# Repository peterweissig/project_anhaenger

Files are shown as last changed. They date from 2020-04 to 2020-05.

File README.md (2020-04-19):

# Anhaenger
Zeichnungen und Ideen zum Reise- und Transportanhänger

## Ziele
Der Anhänger soll ein **Transportanhänger** bleiben. \
Es müssen also alle Einbauten entweder herausnehmbar oder wegklappbar sein.

Darüberhinaus soll er als Schlaf- und **Campinganhänger** genutzt werden. \
Hierfür benötigt er Fenster, eine Liegefläche und mind. einen Klapptisch.

## Skizzen

Details siehe [Skizzen](Skizzen/)

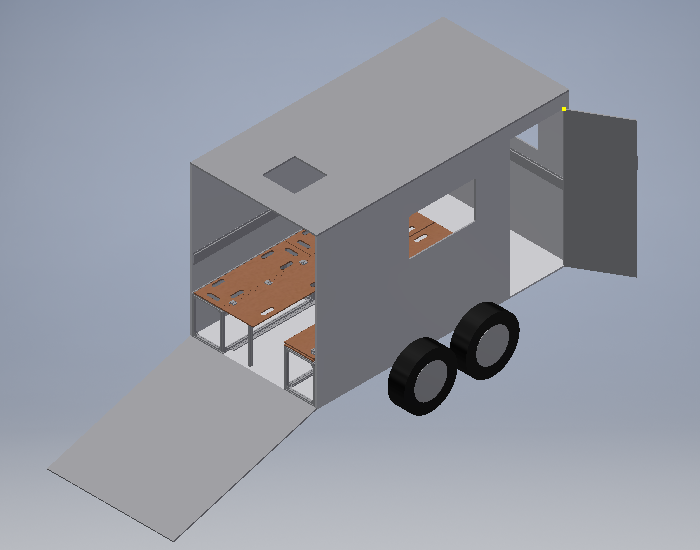
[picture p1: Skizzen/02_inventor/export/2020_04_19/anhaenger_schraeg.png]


## Aktueller Stand
Basis ist ein 2,0t Anhänger vom Humbaur:

* [HK 203015-18P](https://werksverkauf.humbaur.com/anhaenger/kofferanhaenger/kofferanhaenger-detailansicht/modell/hk-203015-18p)
* Innengröße (LxBxH): 3x1,5x1,8m
* Tonnage: 615kg (Leermasse) zu 2,0t
* 100km/h Zulassung (extra Stoßdämpfer)
* Tandemachse mit 15 Zoll Reifen
* Heckklappe für 500kg

Statische Einbauten:

* Dachfenster: Mini Heki von Dometic
* 2 Fenster: Dometic S4
* Klappbarer Tisch

Liege- und Sitzgruppe:

* Eigenkonstruktion
* 2 halbe Liegeflächen (2,20m x 0,75m)
* abklappbar zu 2 Sitzbänken (2,20m x 0,40m)
* je Seite 2 (unabhängige) Elemente (a 1,10m)

## Inspiration
### Dreamboxxx
[Artikel auf adventuremedia4u.de](https://www.adventuremedia4u.de/caravans/offroadanhaenger/dreamboxx.html) \
[Forenbeitrag bei Landcruiserfreunde.de](https://landcruiserfreunde.de/viewtopic.php?f=25&t=1255)

* Kleine Koffer zum Schlafen und Transportieren
* um 2011 _(Firma existiert evtl. nicht mehr)_

### lafalau
[Kurzbeschreibung mit Bildern](http://laufalau.com/10-camping) \
[Beitrag bei wohnwagen-forum.de](https://wohnwagen-forum.de/index.php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)
    
* Basis ist ein Tandem-Koffer von Unsinn
* Kühlkoffer (40mm PU isoliert)
* 3t zGG
* Boden zusätzlich: 20mm Dämmung & 18mm OSB-Platte
* Hinzugefügt: Seitentür, Seitenfenster, Dachfenster
* Einbauten: Küche, Heizung, Solarmodul, Markise,
  Duschkabine, Abwassertank, Windabweise mit Gasflaschen,
  Trittstufen, ...
* Solarzellen, Batterie, Management
* Kostenpunkt 19.300€
    * Airline Zurrschinen 4x2m: 170€
    * Matrazen 2x 80x200cm: 105€
    * Dometic Seitz S4 Fenster: 1.300€ \
      (2x Schlafen, 2x Wohnen, 2x Dachhaube)

### Godes Ausbaublog
[Beitrag bei womobox.de](http://www.womobox.de/phpBB2/viewtopic.php?t=7486)

* Basis ist ein Tandemkoffer
* Kühlkoffer (40mm PU isoliert)
* 3,5t zGG

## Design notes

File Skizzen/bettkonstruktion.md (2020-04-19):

# Bettkonstruktionen
## aktueller Entwurf (V3)
* [Technische Zeichnung](02_inventor/export/2020_04_19/bett_V3/bett_V3_zeichnung.pdf)
* Sitzreihe mit statischer Breite von **38cm**
* Klappteil
    * 36,5cm breit
    * ohne Rahmenkonstruktion aus Aluprofilen
    * wird **nach oben** weggeklappt
* Verbindung über 3 Plastewinkel mit 2 je Schraublöchern

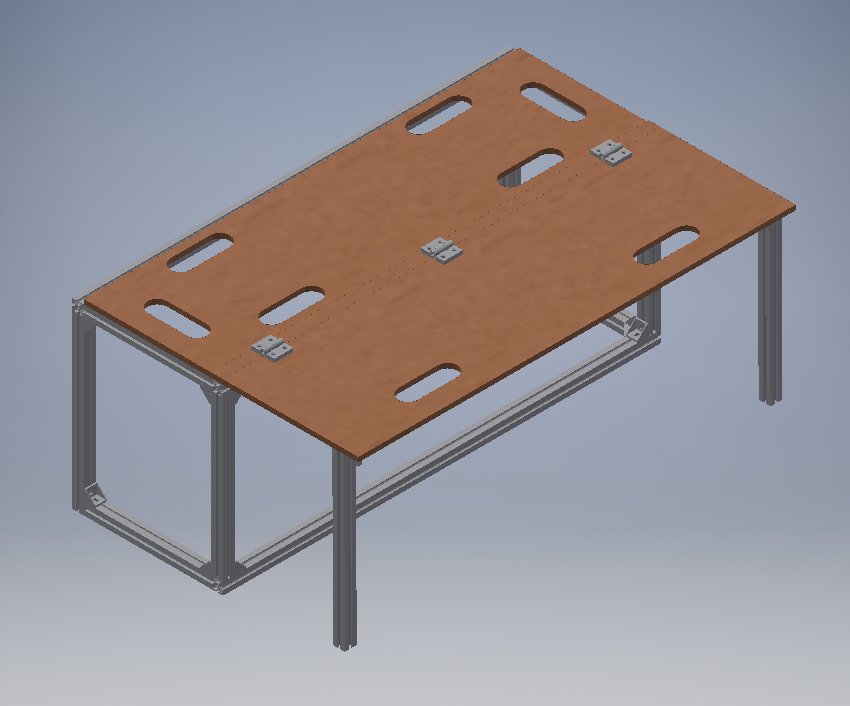
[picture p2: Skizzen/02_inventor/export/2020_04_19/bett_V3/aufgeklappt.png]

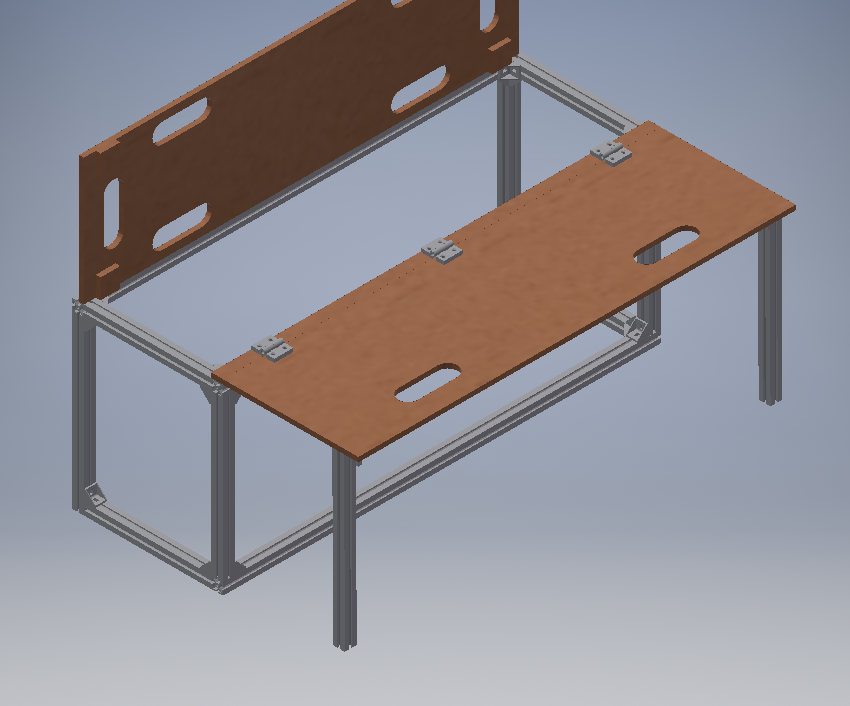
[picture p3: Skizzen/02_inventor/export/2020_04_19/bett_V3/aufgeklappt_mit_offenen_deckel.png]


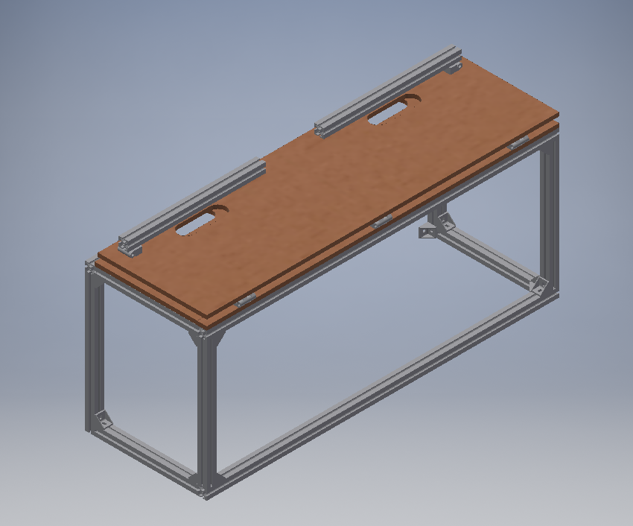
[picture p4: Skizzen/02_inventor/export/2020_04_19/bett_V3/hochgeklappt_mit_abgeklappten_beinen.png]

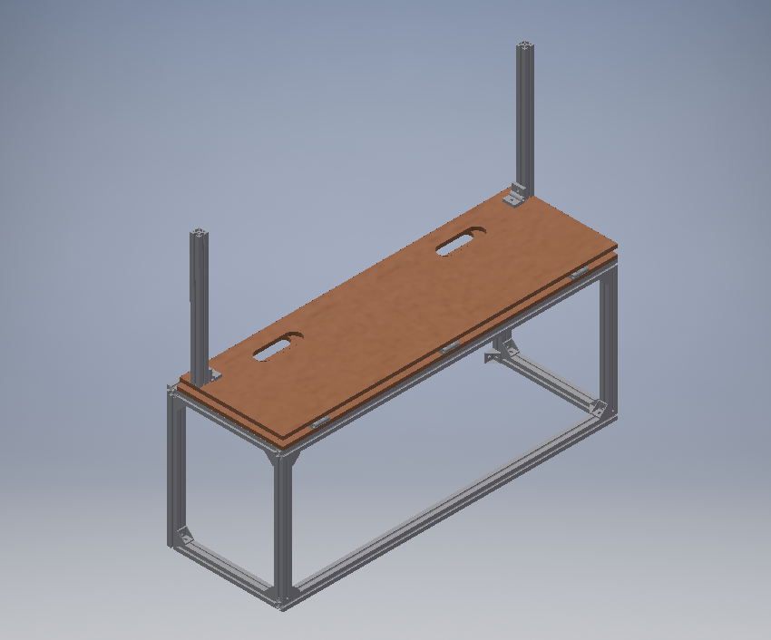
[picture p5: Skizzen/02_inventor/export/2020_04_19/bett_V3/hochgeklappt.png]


## Verison 2
* Sitzreihe mit statischer Breite von 36cm
* Klappteil
    * Rahmenkonstruktion aus Aluprofilen _(31cm breit)_
    * wird nach unten weggeklappt
    * _kann auch vertikal hochgeklappt werden_
* Verbindung über 2 (teure) Aluwinkel

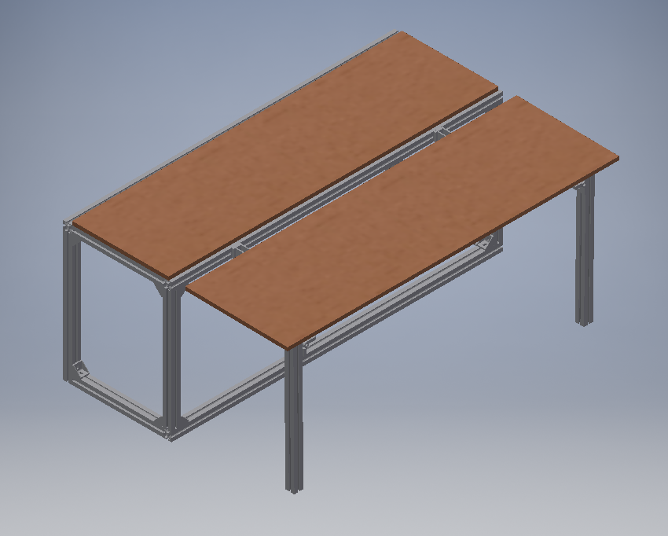
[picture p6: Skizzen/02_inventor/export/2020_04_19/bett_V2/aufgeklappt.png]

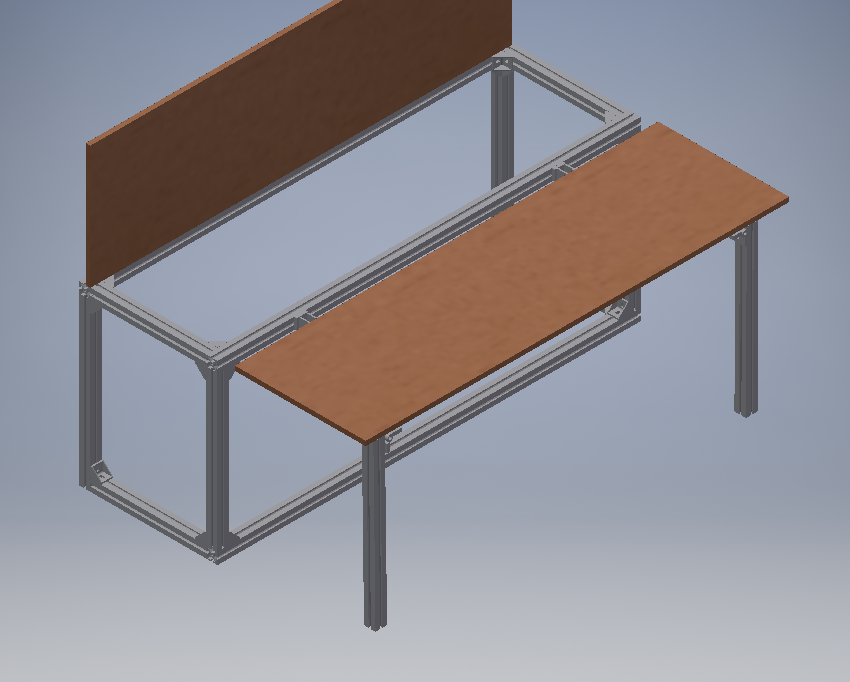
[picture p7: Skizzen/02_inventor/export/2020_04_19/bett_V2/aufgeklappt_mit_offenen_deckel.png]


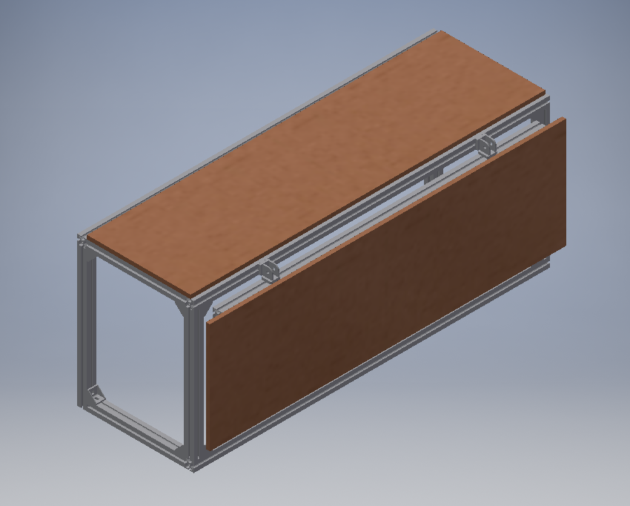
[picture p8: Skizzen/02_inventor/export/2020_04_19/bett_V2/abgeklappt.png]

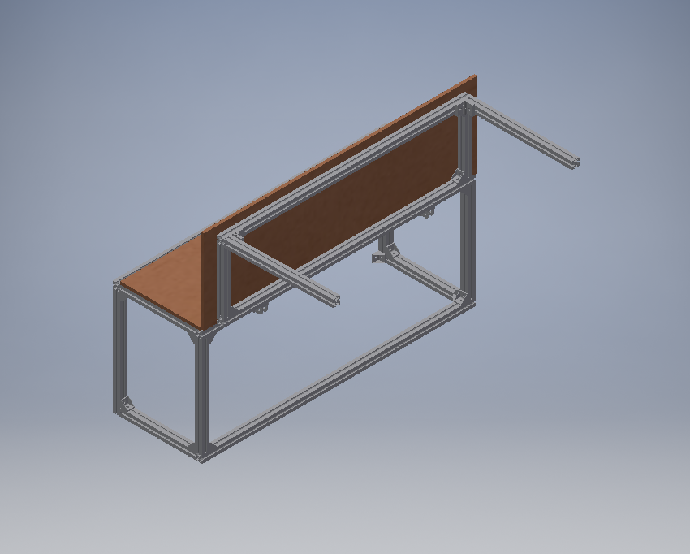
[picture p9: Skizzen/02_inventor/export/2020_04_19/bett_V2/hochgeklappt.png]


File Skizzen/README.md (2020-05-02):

# Skizzen des Anhängers

## aktueller Entwurf
* mit [Autodesk Inventor](https://de.wikipedia.org/wiki/Autodesk_Inventor)
* Tandemanhänger
* Seitentür rechts
* Fenster rechts und vorne
* mit Dachfenster
* [verschiedene Bettkonstruktionen](bettkonstruktion.md) aus Aluprofilen
* **die Konstruktion ist noch nicht fertig**



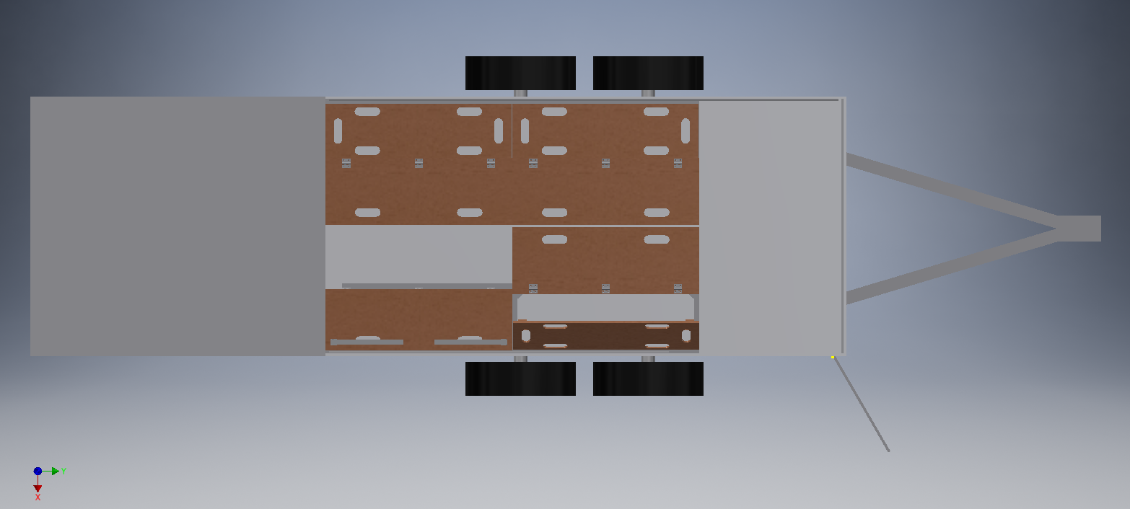
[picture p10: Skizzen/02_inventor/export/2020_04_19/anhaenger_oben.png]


## Erste Skizzen
* mit [SweetHome3D](http://www.sweethome3d.com/) gezeichnet - siehe auch [Ubuntu-Wiki](https://wiki.ubuntuusers.de/Sweet_Home_3D/)
* einachsiger Anhänger
* Seitentür rechts
* Fenster rechts und links
* kein Dachfenster
* Bettkonstruktion aus Holz und ähnlich der Dreamboxxx

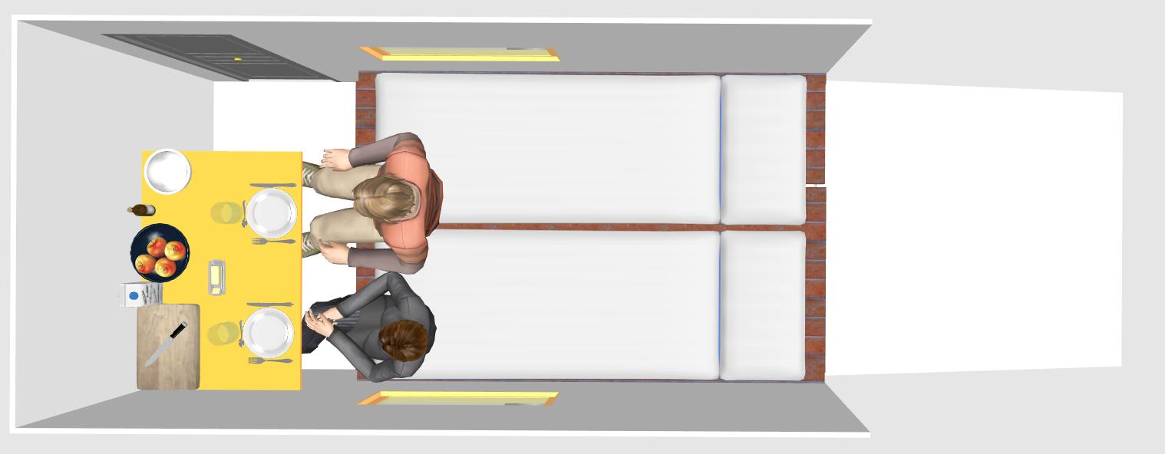
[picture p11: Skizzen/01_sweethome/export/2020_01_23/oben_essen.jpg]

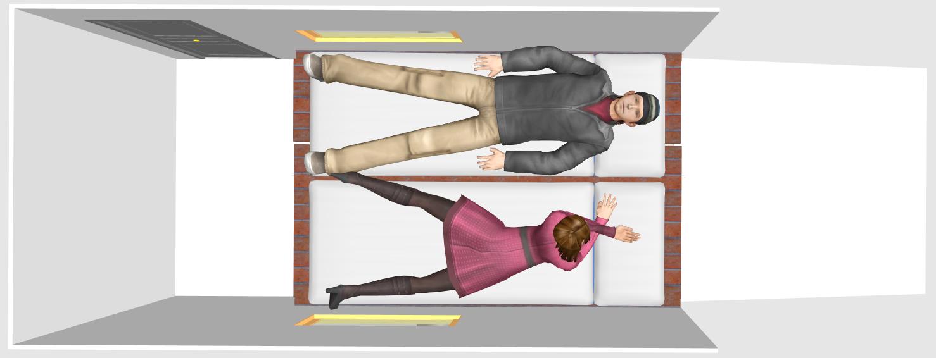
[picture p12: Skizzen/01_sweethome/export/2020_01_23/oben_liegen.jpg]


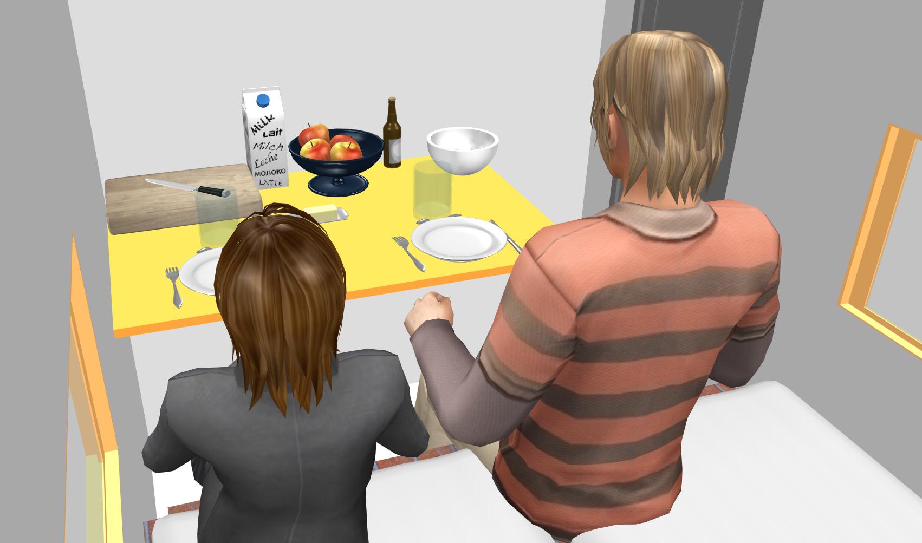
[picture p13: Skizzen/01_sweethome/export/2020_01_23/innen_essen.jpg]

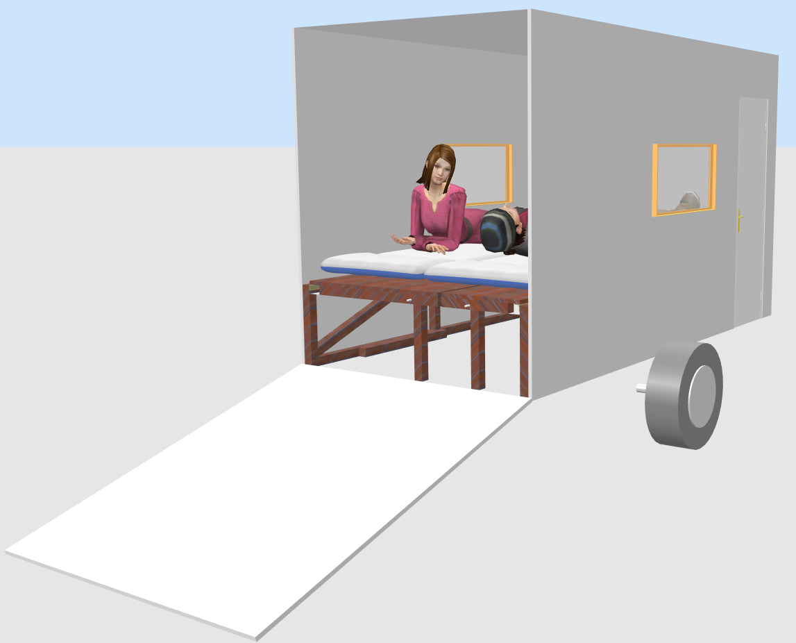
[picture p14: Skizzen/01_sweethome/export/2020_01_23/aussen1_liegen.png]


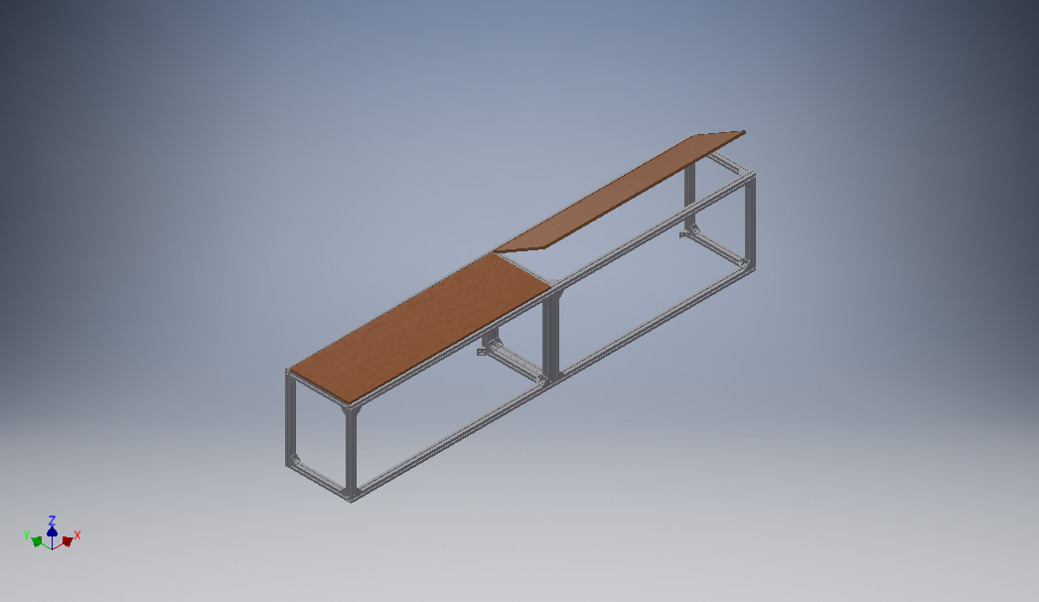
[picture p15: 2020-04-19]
Skizzen/02_inventor/export/2020_04_13/bett_V2_sitzbank_mit_deckel.png

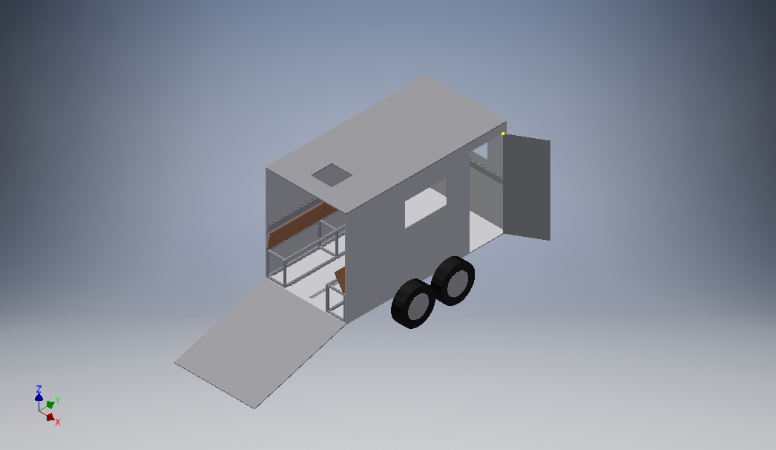
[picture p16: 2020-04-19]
Skizzen/02_inventor/export/2020_03_29/anhaenger_gesamt3.png

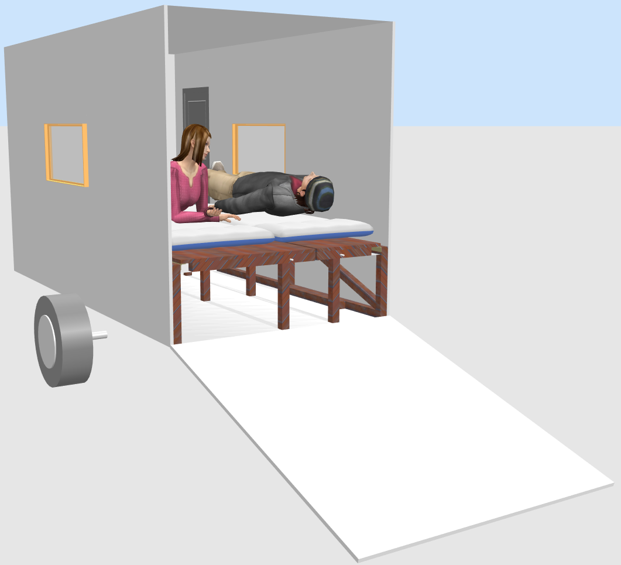
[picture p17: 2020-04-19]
Skizzen/01_sweethome/export/2020_01_23/aussen2_liegen.png

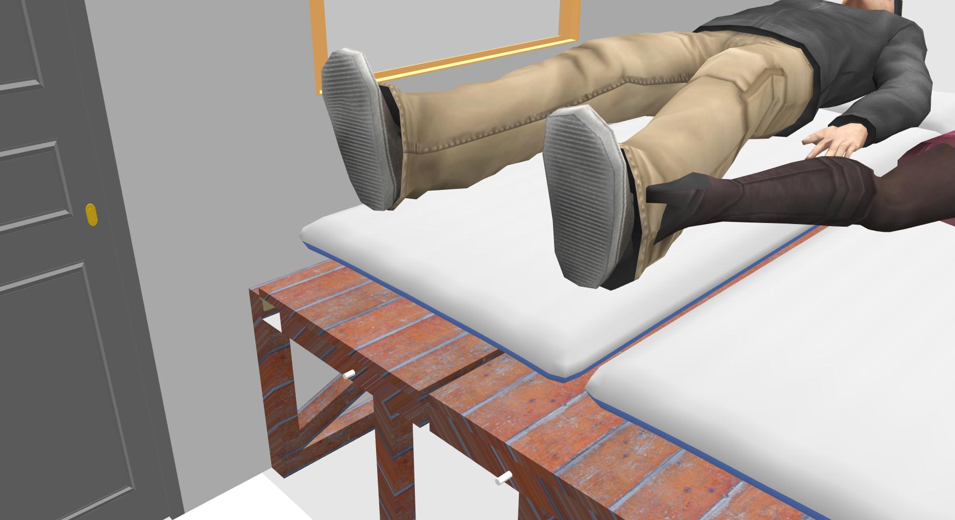
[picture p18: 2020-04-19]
Skizzen/01_sweethome/export/2020_01_23/innen_liegen.jpg

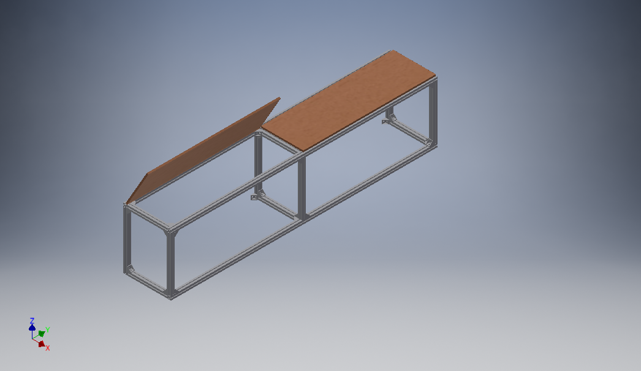
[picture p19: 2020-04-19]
Skizzen/02_inventor/export/2020_04_13/bett_V1_sitzbank_mit_deckel.png

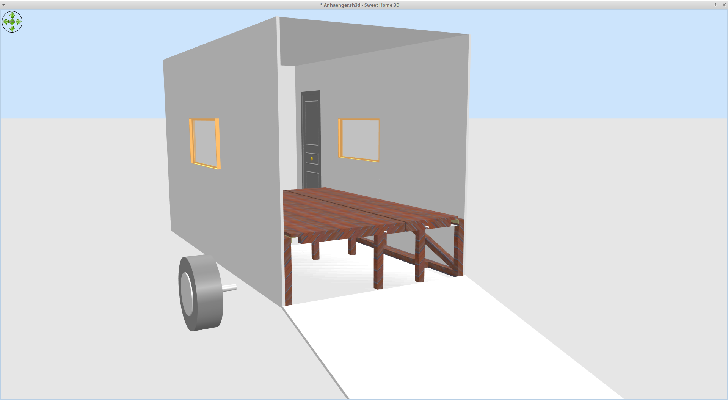
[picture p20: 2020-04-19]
Skizzen/01_sweethome/export/2020_01_22/screenshot/Ansicht_von_Aussen2_zu.png

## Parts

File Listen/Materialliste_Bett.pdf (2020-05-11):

## Bettgestell

Peter Weissig | Seite 1 von 2 | 11.05.2020
Bezeichnung | Art.-Nr. | pro Element | Gesamt | Einzelpreis | Gesamtpreis
63009-SZ1 | 5 | 20 | 9,60 € | 191,99 €
63009-SZ1 | 2 | 8 | 3,91 € | 31,28 €
63009-SZ1 | 2 | 8 | 3,88 € | 31,04 €
63009-STLS-0400 | 2 | 8 | 3,30 € | 26,41 €
63009-SZ1 | 4 | 16 | 2,97 € | 47,53 €
63009-SZ1 | 2 | 8 | 2,63 € | 21,03 €
349,28 €
Bezeichnung | Art.-Nr. | pro Element | Gesamt | Einzelpreis | Gesamtpreis
LP30107 | 2 | 8 | 0,87 € | 6,95 €
62514 | 2 | 8 | 2,10 € | 16,82 €
| 62385-BS | 30 | 120 | 1,64 € | 196,80 €
Bank | 20
Wandbefestigung | 2
Klappe | 4
Beine | 4
64006-1 | 5 | 20 | 2,40 € | 48,00 €
Klappe | 3
Beine | 2
| 62354-VK | 18 | 100 | 0,23 € | 23,39 €
Scharniere | 12 | *
Winkel Klappe | | 12
Beine | -6
| DIN7991-A2-M6X16 | 18 | 100 | 0,05 € | 4,95 €
Scharniere | 12 | *
Beine | 6
DIN7991-A2-M6X18 | 2 | 10 | 0,20 € | 2,03 €
Beine | 2 | *
| DIN7984-A2-M6X12 | 14 | 100 | 0,06 € | 6,43 €
Winkel | 10 | *
Beine | 4
305,37 €

* aufgerundet, da Verbauchsmaterial und/oder wegen Mengenrabatt

Bezeichnung | Art.-Nr. | pro Element | Gesamt | Einzelpreis | Gesamtpreis
62491 | 9,26 | 37 | 4,40 € | 162,80 €
Bank | 2,84 | *
Klappe | 2,76
Schutz Klappe | | 0,8
Schutz Beine | | 0,5
Schutz Rückwand | | 0,86
Schutz Seite | | 1,5
Versandkosten (ca.) | 1 | 1 | 19,66 € | 19,66 €
182,46 €

* leicht abgerundet, da Verkauf nur auf ganze Meter

Gesamtsumme der Bestellung | 837,11 €
Einzelpreis pro Element | 209,28 €

Aluprofil – 110 cm
Aluprofil – 43 cm
Aluprofil – 42,7 cm (https://www.dold-mechatronik.de/Aluminiumprofil-30x30L-I-Typ-Nut-6-ZUSCHNITT-bis-1200-mm-850-EUR-m-025-EUR-pro-Schnitt)
Aluprofil – 40 cm (https://www.dold-mechatronik.de/Aluminiumprofil-30x30L-I-Typ-Nut-6-Standardlaengen-825-EUR-m-400mm)
Aluprofil – 32 cm
Aluprofil – 28 cm (https://www.dold-mechatronik.de/Aluminiumprofil-30x30L-I-Typ-Nut-6-ZUSCHNITT-bis-1200-mm-850-EUR-m-025-EUR-pro-Schnitt)

Aluplatte – 3 Loch (https://www.dold-mechatronik.de/Verbinderplatte-58x58mm-3-Loch-Alu-gelasert)
Aluplatte – 8 Loch (https://www.dold-mechatronik.de/Verbinderplatte-58x118-8-loch-gelasert-blank)
Winkelsatz (https://www.dold-mechatronik.de/Winkel-30-I-Typ-Nut-6-inkl-Befestigungssatz)

Scharnier leicht (https://www.dold-mechatronik.de/Scharnier-Kunststoff-leicht-30-30_1)

Nutensteine (https://www.dold-mechatronik.de/Nutenstein-mit-Steg-I-Typ-Nut-6-Gewindedurchmesser-M6)

Schraube – 16mm Senkkopf (https://www.dold-mechatronik.de/DIN-7991-Senkschraube-mit-Innensechskant-A2-M6X16)

Schraube – 18mm Senkkopf (https://www.dold-mechatronik.de/DIN-7991-Senkschraube-mit-Innensechskant-A2-M6X18)

Schraube – 12mm Zylinderkopf (https://www.dold-mechatronik.de/DIN-7984-Zylinderschraube-mit-Innensechskant-und-niedrigem-Kopf-Edelstahl-A2-M6X12)

Abdeckung (https://www.dold-mechatronik.de/Abdeckprofil-Kunststoff-NBR-I-Typ-Nut-6-ca-1000-mm)

### https://www.dold-mechatronik.de/

## Deckplatten

Peter Weissig | Seite 2 von 2 | 11.05.2020

* alle Platten waren Zuschnitt im Hornbach für 30,71€/m²

Gesamtsumme | 99,32 €
Einzelpreis pro Element | 24,83 €

### https://www.hornbach.de/

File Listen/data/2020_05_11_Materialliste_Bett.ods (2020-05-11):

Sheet: Bettgestell
Bezeichnung | Art.-Nr. | pro Element | Gesamt | Einzelpreis | Gesamtpreis
Aluprofil – 110 cm (https://www.dold-mechatronik.de/Aluminiumprofil-30x30L-I-Typ-Nut-6-ZUSCHNITT-bis-1200-mm-850-EUR-m-025-EUR-pro-Schnitt) | 63009-SZ1 | 5 | 20 | 9,60 € | 191,99 €
Aluprofil – 43 cm (https://www.dold-mechatronik.de/Aluminiumprofil-30x30L-I-Typ-Nut-6-ZUSCHNITT-bis-1200-mm-850-EUR-m-025-EUR-pro-Schnitt) | 63009-SZ1 | 2 | 8 | 3,91 € | 31,28 €
Aluprofil – 42,7 cm (https://www.dold-mechatronik.de/Aluminiumprofil-30x30L-I-Typ-Nut-6-ZUSCHNITT-bis-1200-mm-850-EUR-m-025-EUR-pro-Schnitt) | 63009-SZ1 | 2 | 8 | 3,88 € | 31,04 €
Aluprofil – 40 cm (https://www.dold-mechatronik.de/Aluminiumprofil-30x30L-I-Typ-Nut-6-Standardlaengen-825-EUR-m-400mm) | 63009-STLS-0400 | 2 | 8 | 3,30 € | 26,41 €
Aluprofil – 32 cm (https://www.dold-mechatronik.de/Aluminiumprofil-30x30L-I-Typ-Nut-6-ZUSCHNITT-bis-1200-mm-850-EUR-m-025-EUR-pro-Schnitt) | 63009-SZ1 | 4 | 16 | 2,97 € | 47,53 €
Aluprofil – 28 cm (https://www.dold-mechatronik.de/Aluminiumprofil-30x30L-I-Typ-Nut-6-ZUSCHNITT-bis-1200-mm-850-EUR-m-025-EUR-pro-Schnitt) | 63009-SZ1 | 2 | 8 | 2,63 € | 21,03 €
 |  |  |  |  | 349,28 €
Bezeichnung | Art.-Nr. | pro Element | Gesamt | Einzelpreis | Gesamtpreis
Aluplatte – 3 Loch (https://www.dold-mechatronik.de/Verbinderplatte-58x58mm-3-Loch-Alu-gelasert) | LP30107 | 2 | 8 | 0,87 € | 6,95 €
Aluplatte – 8 Loch (https://www.dold-mechatronik.de/Verbinderplatte-58x118-8-loch-gelasert-blank) | 62514 | 2 | 8 | 2,10 € | 16,82 €
Winkelsatz (https://www.dold-mechatronik.de/Winkel-30-I-Typ-Nut-6-inkl-Befestigungssatz) | 62385-BS | 30 | 120 | 1,64 € | 196,80 €
Bank |  | 20
Wandbefestigung |  | 2
Klappe |  | 4
Beine |  | 4
Scharnier leicht (https://www.dold-mechatronik.de/Scharnier-Kunststoff-leicht-30-30_1) | 64006-1 | 5 | 20 | 2,40 € | 48,00 €
Klappe |  | 3
Beine |  | 2
Nutensteine (https://www.dold-mechatronik.de/Nutenstein-mit-Steg-I-Typ-Nut-6-Gewindedurchmesser-M6) | 62354-VK | 18 | 100 | 0,23 € | 23,39 €
Scharniere |  | 12 | *
Winkel Klappe |  | 12
Beine |  | -6
Schraube – 16mm Senkkopf (https://www.dold-mechatronik.de/DIN-7991-Senkschraube-mit-Innensechskant-A2-M6X16) | DIN7991-A2-M6X16 | 18 | 100 | 0,05 € | 4,95 €
Scharniere |  | 12 | *
Beine |  | 6
Schraube – 18mm Senkkopf (https://www.dold-mechatronik.de/DIN-7991-Senkschraube-mit-Innensechskant-A2-M6X18) | DIN7991-A2-M6X18 | 2 | 10 | 0,20 € | 2,03 €
Beine |  | 2 | *
Schraube – 12mm Zylinderkopf (https://www.dold-mechatronik.de/DIN-7984-Zylinderschraube-mit-Innensechskant-und-niedrigem-Kopf-Edelstahl-A2-M6X12) | DIN7984-A2-M6X12 | 14 | 100 | 0,06 € | 6,43 €
Winkel |  | 10 | *
Beine |  | 4
 |  |  |  |  | 305,37 €
* aufgerundet, da Verbauchsmaterial und/oder wegen Mengenrabatt
Bezeichnung | Art.-Nr. | pro Element | Gesamt | Einzelpreis | Gesamtpreis
Abdeckung (https://www.dold-mechatronik.de/Abdeckprofil-Kunststoff-NBR-I-Typ-Nut-6-ca-1000-mm) | 62491 | 9,26 | 37 | 4,40 € | 162,80 €
Bank |  | 2,84 | *
Klappe |  | 2,76
Schutz Klappe |  | 0,8
Schutz Beine |  | 0,5
Schutz Rückwand |  | 0,86
Schutz Seite |  | 1,5
Versandkosten (ca.) |  | 1 | 1 | 19,66 € | 19,66 €
 |  |  |  |  | 182,46 €
* leicht abgerundet, da Verkauf nur auf ganze Meter
https://www.dold-mechatronik.de/ |  | Gesamtsumme der Bestellung |  |  | 837,11 €
 |  | Einzelpreis pro Element |  |  | 209,28 €

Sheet: Deckplatten
Bezeichnung | Anzahl | Länge in cm | Breite in cm | Fläche in m² | Einzelpreis | Gesamtpreis
Siebdruckplatte 12mm (https://www.hornbach.de/shop/Siebdrucksperrholz-Birke-Sieb-Film-1250x2500x12-mm-Zuschnitt-online-reservierbar/5017757/artikel.html) | 4 | 110 | 37,5 | 0,4125 | 12,67 € | 50,68 €
Siebdruckplatte 12mm (https://www.hornbach.de/shop/Siebdrucksperrholz-Birke-Sieb-Film-1250x2500x12-mm-Zuschnitt-online-reservierbar/5017757/artikel.html) | 4 | 110 | 36 | 0,396 | 12,16 € | 48,64 €
 |  |  |  |  |  | 99,32 €
* alle Platten waren Zuschnitt im Hornbach für 30,71€/m²
https://www.hornbach.de/ |  | Gesamtsumme |  |  |  | 99,32 €
 |  | Einzelpreis pro Element |  |  |  | 24,83 €

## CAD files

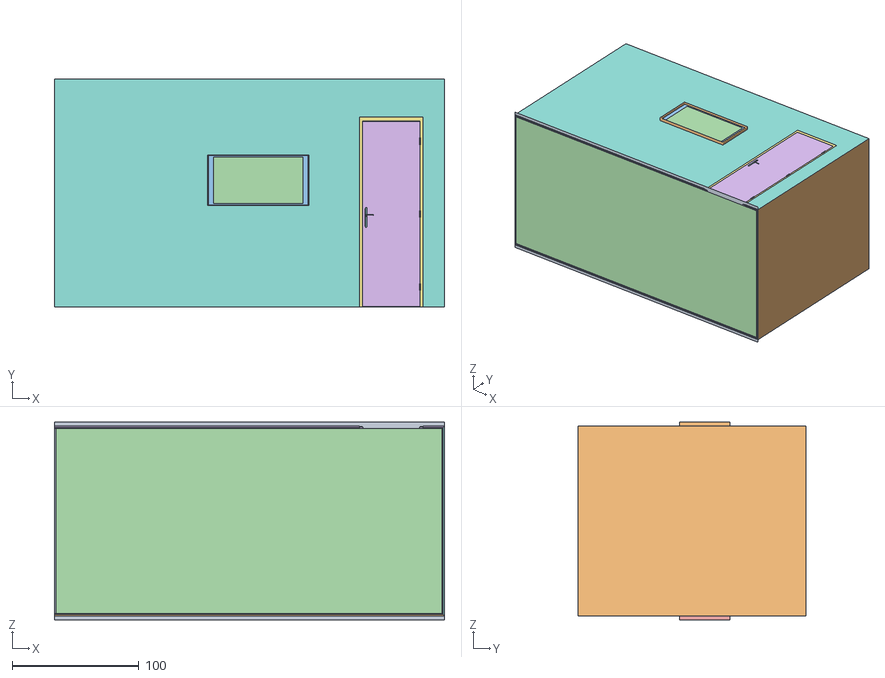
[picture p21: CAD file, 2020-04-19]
Skizzen/01_sweethome/details/anhaenger/teil1_grundkoerper/anhaenger_aufbau_teil1.obj
308.0 x 180.0 x 156.0
ground_1
wall_1_2
wall_1_3
wall_1_4
wall_1_5
wall_1_6
wall_1_7
wall_2_8
wall_2_9
wall_2_10
wall_2_11
wall_2_12
wall_2_13
wall_3_14
wall_3_15
wall_3_16
wall_3_17
wall_3_18
wall_3_19
room_4_20
room_4_21
frameOutside_22
frame_23
sweethome3d_hinge_1_3_2_24
sweethome3d_hinge_1_3_25
sweethome3d_hinge_1_2_2_26
sweethome3d_hinge_1_2_27
sweethome3d_hinge_1_1_2_28
sweethome3d_hinge_1_1_29
sweethome3d_opening_on_hinge_1_door_30
sweethome3d_opening_on_hinge_1_handle_7_31
sweethome3d_opening_on_hinge_1_handle_32
sweethome3d_opening_on_hinge_1_doorOutside_33
Tour_Fenetre_34
Fenetre_1_35
sweethome3d_window_pane_36
Tour_Fenetre_37
Fenetre_1_38
sweethome3d_window_pane_39

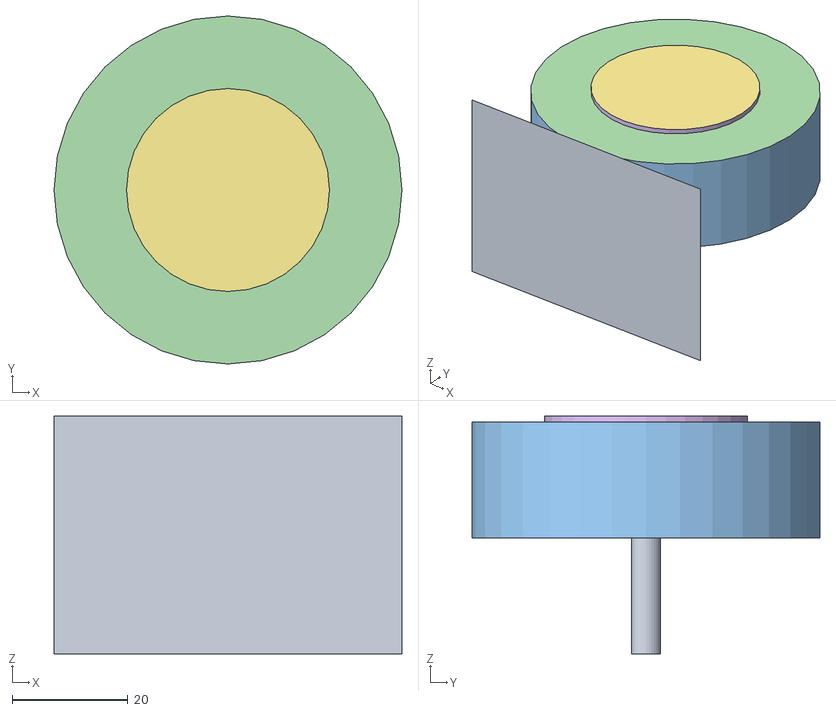
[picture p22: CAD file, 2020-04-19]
Skizzen/01_sweethome/details/anhaenger/teil2_raeder/anhaenger_aufbau_teil2.obj
60.0 x 60.0 x 41.0
ground_1

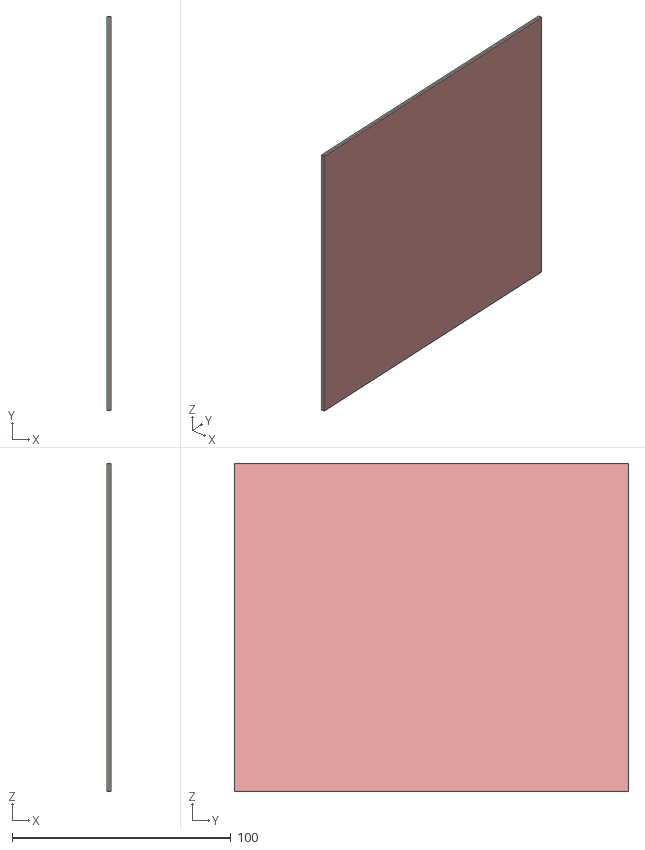
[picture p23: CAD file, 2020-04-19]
Skizzen/01_sweethome/details/anhaenger/teil3_heckklappe/anhaenger_aufbau_teil3.obj
2.00 x 180.0 x 150.0
ground_1
wall_1_2
wall_1_3
wall_1_4
wall_1_5
wall_1_6
wall_1_7

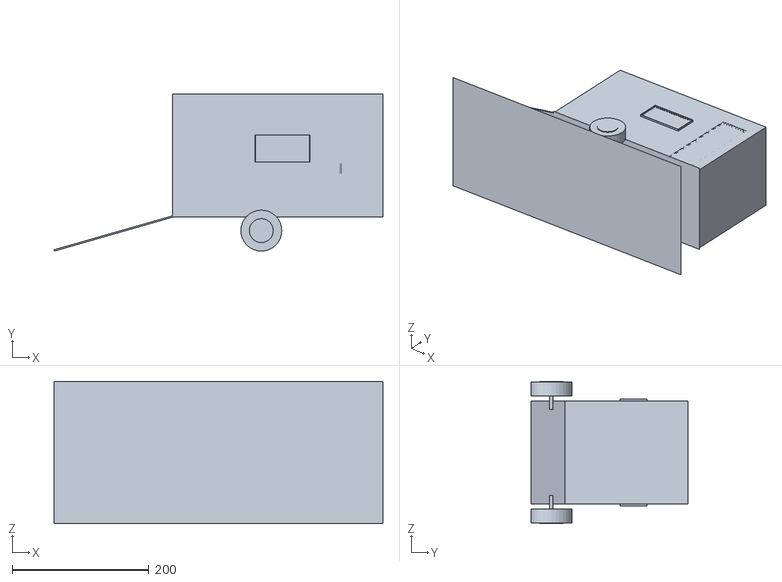
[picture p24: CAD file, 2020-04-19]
Skizzen/01_sweethome/details/anhaenger_aufgeklappt.obj
481.3 x 230.0 x 208.0

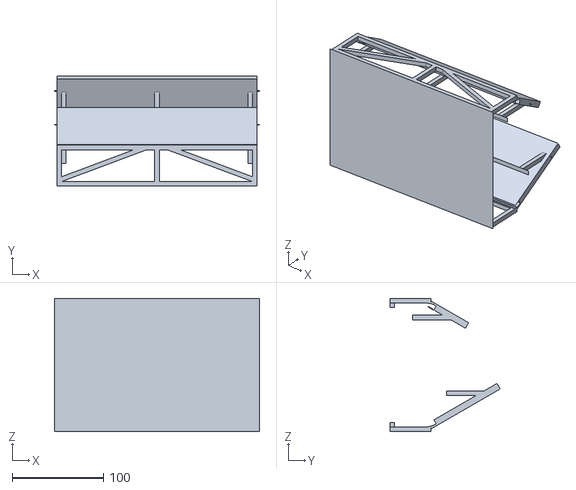
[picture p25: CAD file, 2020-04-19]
Skizzen/01_sweethome/details/bettgestell/anhaenger_bettgestell_aufgeklappt.obj
225.0 x 121.2 x 146.0

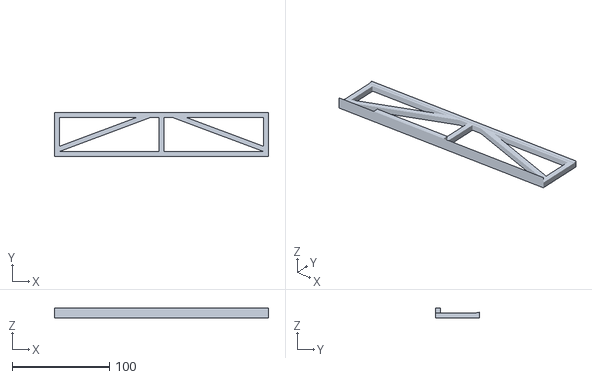
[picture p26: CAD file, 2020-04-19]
Skizzen/01_sweethome/details/bettgestell/teil_1_seitenteil/anhaenger_bettgestell_teil1.obj
220.0 x 45.0 x 10.0

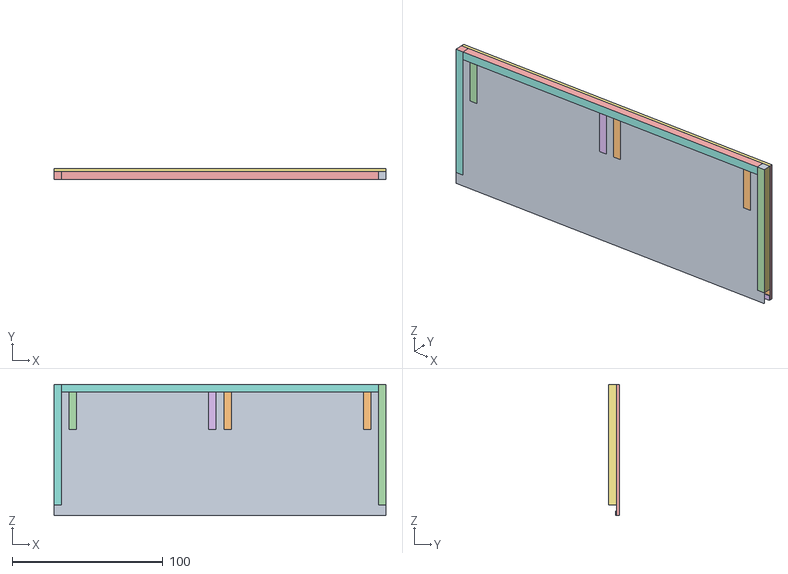
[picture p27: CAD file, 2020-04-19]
Skizzen/01_sweethome/details/bettgestell/teil_2_platte_links/anhaenger_bettgestell_teil2.obj
220.0 x 7.00 x 87.0
ground_1
bottom_2
top_3
left_4
right_5
back_6
front_7
bottom_8
top_9
left_10
right_11
back_12
front_13
bottom_14
top_15
left_16
right_17
back_18
front_19
bottom_20
top_21
left_22
right_23
back_24
front_25
bottom_26
top_27
left_28
right_29
back_30
front_31
bottom_32
top_33
left_34
right_35
back_36
front_37
bottom_38
top_39
left_40
right_41
back_42
front_43
bottom_44
top_45
left_46
right_47
back_48
front_49
bottom_50
top_51
left_52
right_53
back_54
front_55

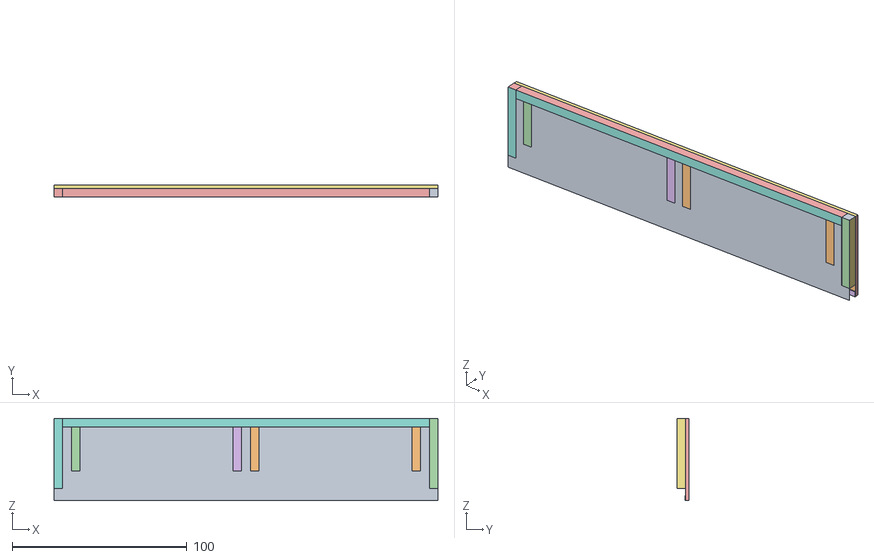
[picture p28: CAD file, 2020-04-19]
Skizzen/01_sweethome/details/bettgestell/teil_3_platte_rechts/anhaenger_bettgestell_teil3.obj
220.0 x 7.00 x 47.0
ground_1
bottom_2
top_3
left_4
right_5
back_6
front_7
bottom_8
top_9
left_10
right_11
back_12
front_13
bottom_14
top_15
left_16
right_17
back_18
front_19
bottom_20
top_21
left_22
right_23
back_24
front_25
bottom_26
top_27
left_28
right_29
back_30
front_31
bottom_32
top_33
left_34
right_35
back_36
front_37
bottom_38
top_39
left_40
right_41
back_42
front_43
bottom_44
top_45
left_46
right_47
back_48
front_49
bottom_50
top_51
left_52
right_53
back_54
front_55

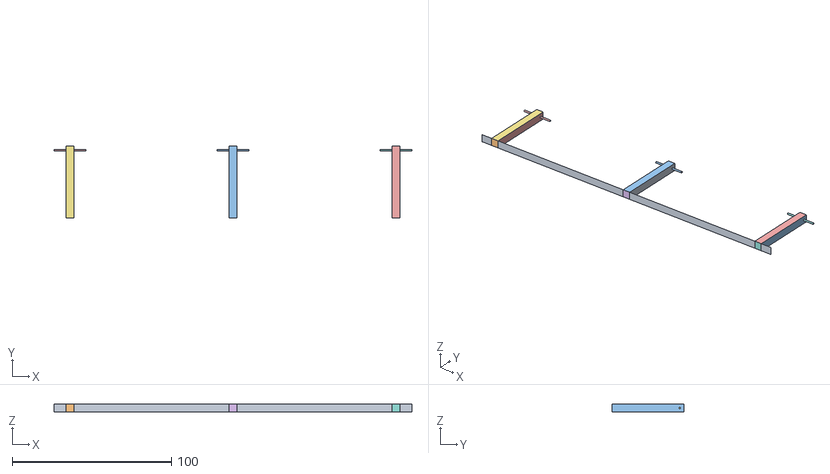
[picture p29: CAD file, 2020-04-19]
Skizzen/01_sweethome/details/bettgestell/teil_4_fuesse/anhaenger_bettgestell_teil4.obj
225.0 x 45.0 x 5.00
ground_1
bottom_2
top_3
left_4
right_5
back_6
front_7
bottom_8
top_9
left_10
right_11
back_12
front_13
bottom_14
top_15
left_16
right_17
back_18
front_19

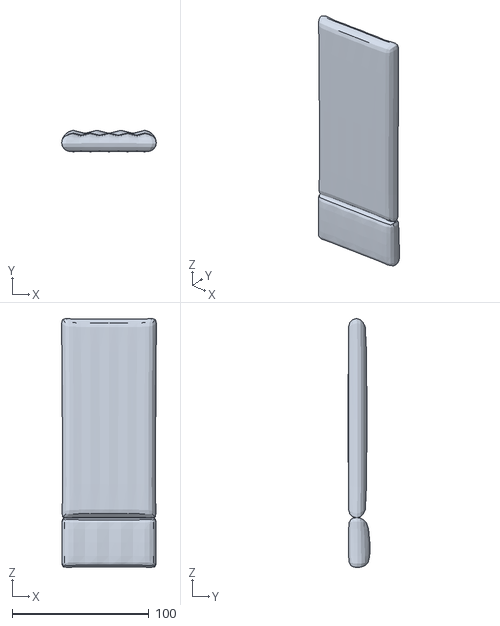
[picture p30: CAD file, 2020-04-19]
Skizzen/01_sweethome/details/matraze_download/air-mattress.obj
69.4 x 15.8 x 181.9

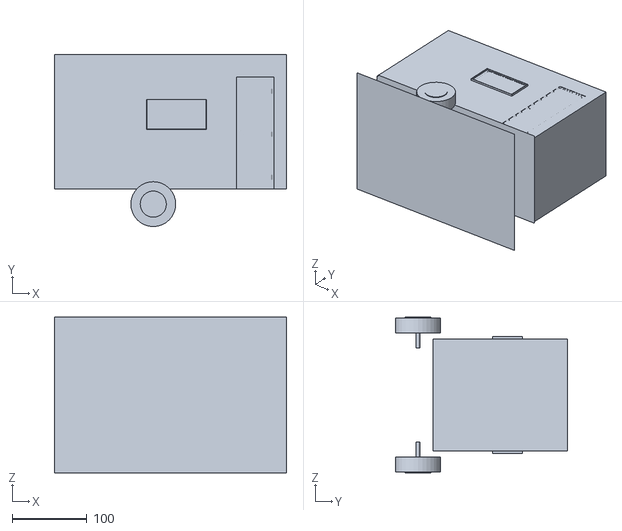
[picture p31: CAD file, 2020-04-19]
Skizzen/01_sweethome/details/anhaenger_zugeklappt.obj
310.0 x 230.0 x 208.0

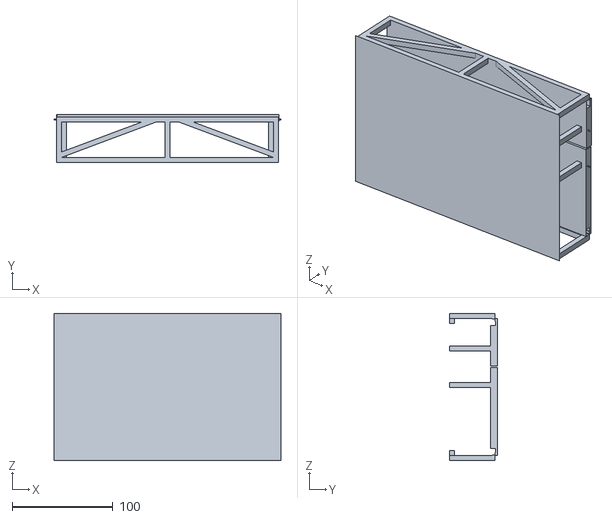
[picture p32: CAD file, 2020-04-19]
Skizzen/01_sweethome/details/bettgestell/anhaenger_bettgestell_zugeklappt.obj
225.0 x 47.4 x 146.0

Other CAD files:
Skizzen/02_inventor/details/bett/bett_V3/bett_V3_zeichnung.dwg
Skizzen/02_inventor/details/bett/bett_V1/bett_V1.iam
Skizzen/02_inventor/details/bett/bett_V1/bett_V1_teil1_sitzbank.iam
Skizzen/02_inventor/details/bett/bett_V1/bett_V1_teil2_deckplatte.ipt
Skizzen/02_inventor/details/bett/bett_V2/bett_V2.iam
Skizzen/02_inventor/details/bett/bett_V2/bett_V2_detail_deckplatte_klappe.ipt
Skizzen/02_inventor/details/bett/bett_V2/bett_V2_doppelt.iam
Skizzen/02_inventor/details/bett/bett_V2/bett_V2_teil1_sitzbank.iam
Skizzen/02_inventor/details/bett/bett_V2/bett_V2_teil2_deckplatte.ipt
Skizzen/02_inventor/details/bett/bett_V2/bett_V2_teil3_klappe.iam
Skizzen/02_inventor/details/bett/bett_V2/bett_V2_teil4_bein.iam
Skizzen/02_inventor/details/bett/bett_V3/bett_V3.iam
Skizzen/02_inventor/details/bett/bett_V3/bett_V3_detail_deckplatte_klappe.ipt
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

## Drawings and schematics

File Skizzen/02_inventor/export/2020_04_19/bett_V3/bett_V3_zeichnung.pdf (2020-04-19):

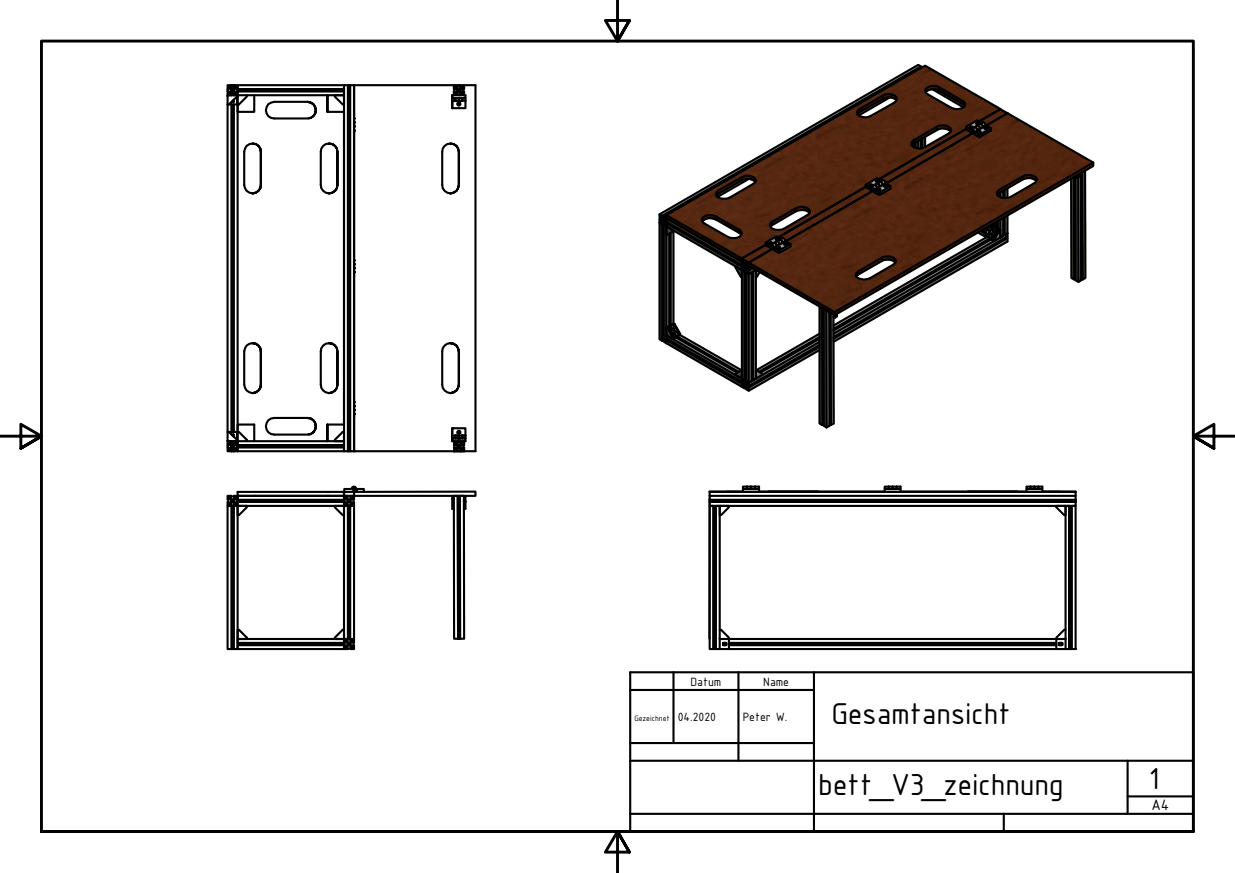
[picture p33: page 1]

Datum | Name | Gesamtansicht

Gezeichnet | 04.2020 | Peter W.

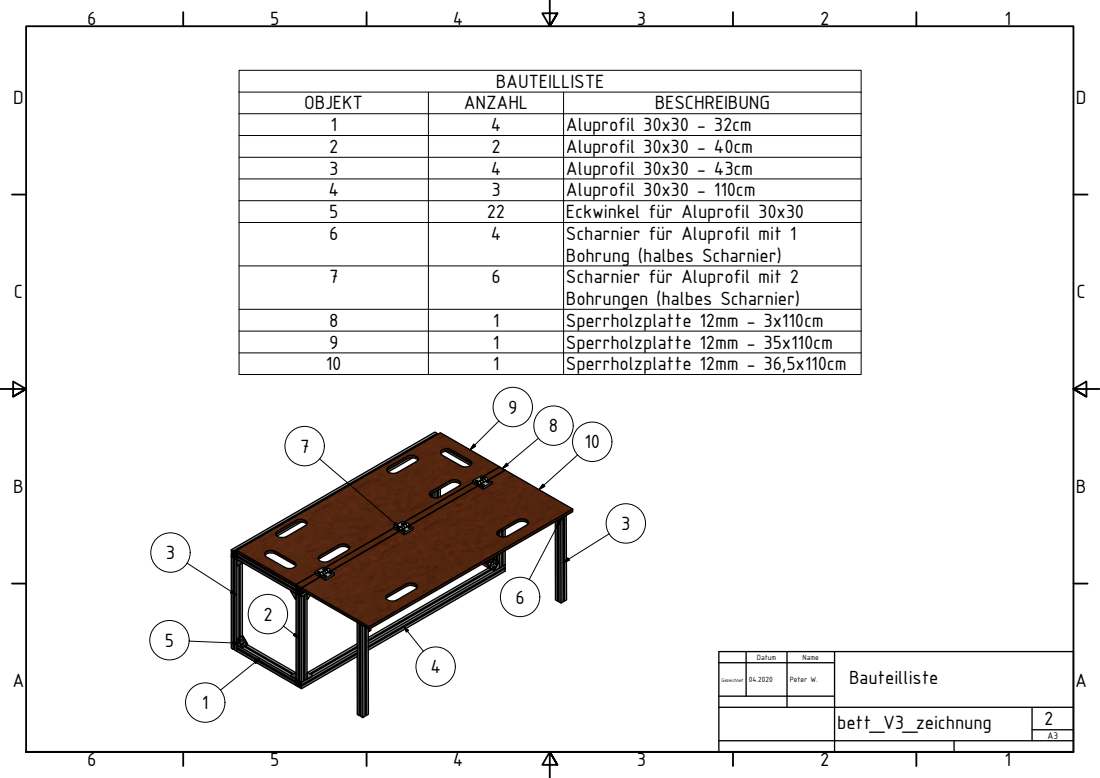
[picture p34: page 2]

O B J E K T | A N Z A H L | B E S C H R EIB U N G
1 | 4 | A l u p r o fil 3 0 x 3 0 -3 2 c m
2 | 2 | A l u p r o fil 3 0 x 3 0 -4 0 c m
3 | 4 | A l u p r o fil 3 0 x 3 0 -4 3 c m
4 | 3 | A l u p r o fil 3 0 x 3 0 -1 1 0 c m
5 | 2 2 | E c k win k e l f ¯ r A l u p r o fil 3 0 x 3 0
6 | 4 | S c h a r nie r f ¯ r A l u p r o fil mit 1 ( ) B o h r u n g h a l b e s S c h a r nie r

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

D a t u m | N a m e | a u t eil lis t e

G e z eic h n e t | 0 4.2 0 2 0 | W. B P e t e r

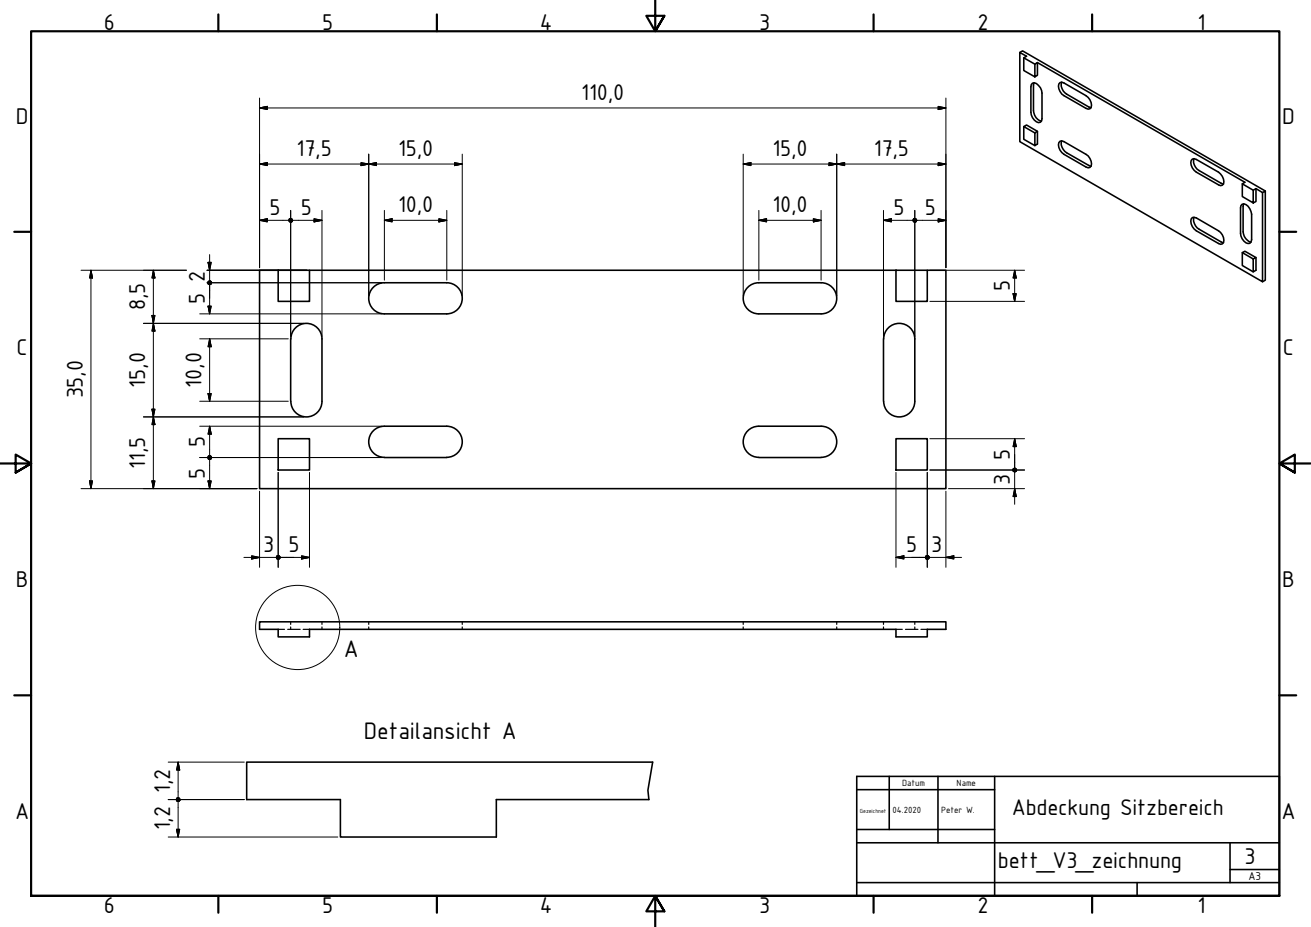
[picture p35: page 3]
Detailansicht A

Datum | Name | Abdeckung Sitzbereich

Gezeichnet | 04.2020 | Peter W.

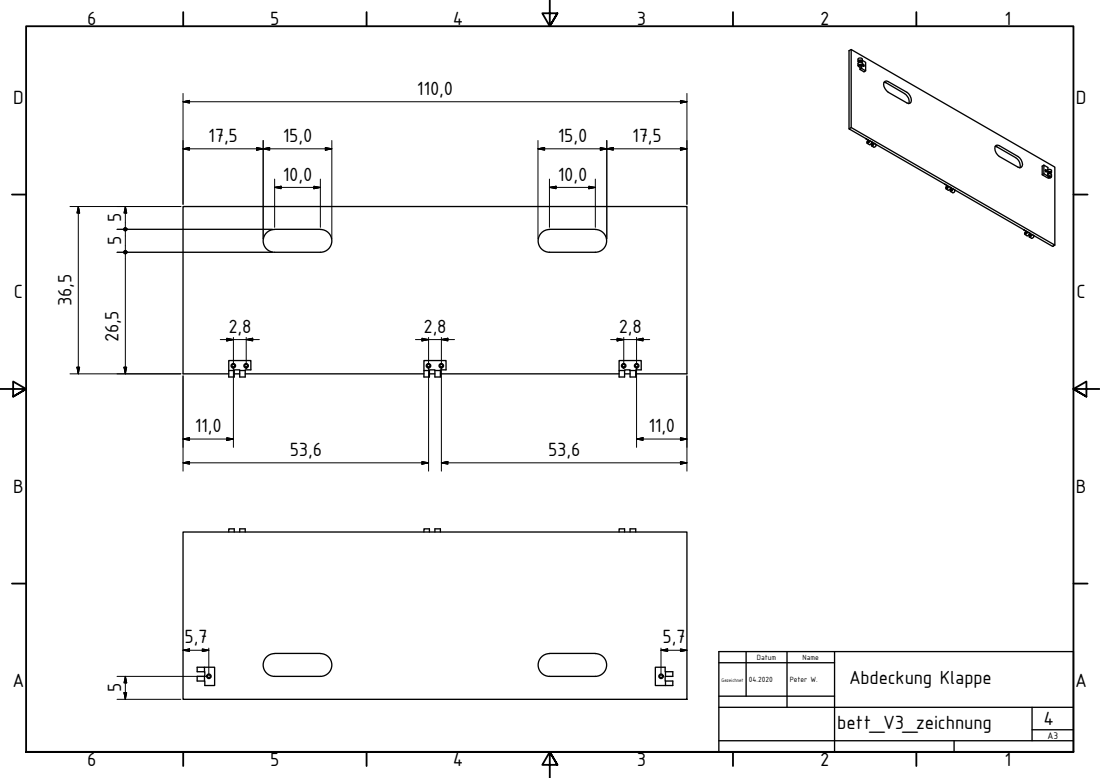
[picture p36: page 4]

Datum | Name | Abdeckung Klappe

Gezeichnet | 04.2020 | Peter W.

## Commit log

2020-04-19 added Skizzen vom Anhänger
    [Boden_airline_eckig.ipt, Boden_airline_rund.ipt, Koffer_ankerschiene_15m.ipt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]
2020-04-19 updated Skizzen (added Bett V3)
    [Boden_airline_eckig.ipt, Boden_airline_rund.ipt, Koffer_ankerschiene_15m.ipt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]
2020-04-19 added Markdown für die verschiedenen Bettkonstruktionen
2020-05-11 added Materialliste Bettgestellt + Aluprofile + Deckplatten
    [2020_05_11_Materialliste_Bett.ods]
